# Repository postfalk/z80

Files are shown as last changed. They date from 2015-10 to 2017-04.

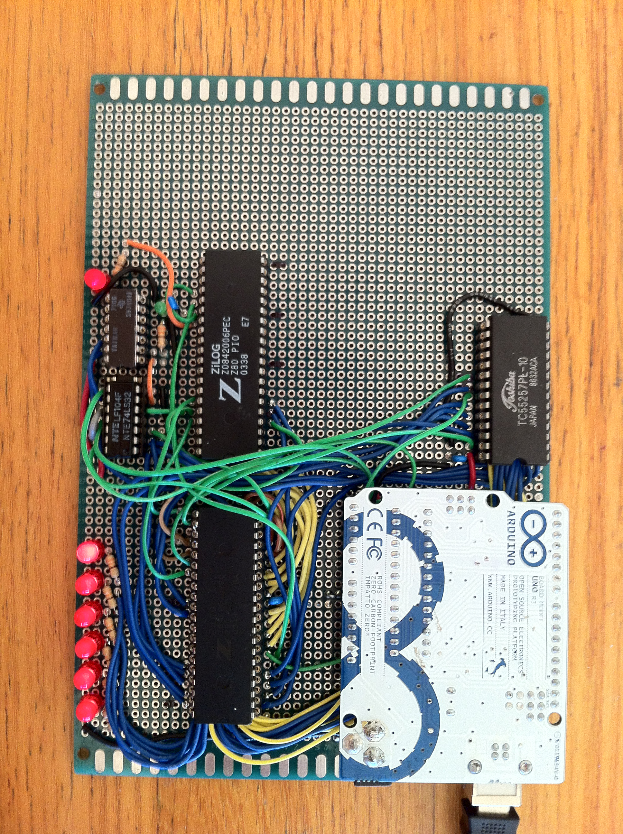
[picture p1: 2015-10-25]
z80_2015_10_25.jpg

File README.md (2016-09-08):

#My Z80 Computer

### Assembler software ####

There is a Z80 assembler in the Ubuntu universe repos!!!

```
sudo apt-get install z80asm 
```

Make sure z80asm is in your executable path. There is also a de-assembler for binaries (z80dasm).

I wrote a simple Python script to automate assembly.

```
python assemble.py -i test.asm
```

In order to review binary hex code install bless:

```
sudo apt-get install bless
```

Most software and examples are written in TASM, I found a compatible project still maintained called ZASM

http://k1.spdns.de/Develop/Projects/zasm/Distributions/

CPM setup

This page proved very useful

http://cpuville.com/cpm_on_new_computer.html

(Currently validating its usefulness)

------------- Much of the below is now obsolete ------------------

**Arduino driven Z80 development**

The Arduino is gone now. Development is fun without it. However, the form factor is still there. Arduino could be used for debugging as needed.

~~The basic idea of this project is to use an Arduino to support the development of a z80 computer system and debug any of its components in the process. The Arduino stands in as ...~~

~~a) reset generator~~
~~b) clock~~
~~c) ROM for the lowest 64byte 0000h-003Fh~~

~~The z80 code is fed from a C array to PORTD, PORTB (with 6pins on an Arduino UNO R3) as address bus, and PORTC simulates the control bus (RD --> PIN4, MRQ --> PIN2, RESET <-- PIN3, CLOCK <-- Pin5). The array index correspondends directly with the z80 system address.~~

~~The z80 board is more or less configured as an Arduino shield (even though bigger, the Arduino is plucked in upside down on top of it). In order to run the board without the Arduino, I created a circuit on an Arduino shield PCB with the reset and clock circuit. Thus, it is possible to go back and forth between normal computer operation and running debug code from Arduino.~~

~~The Arduino emulation runs somewhat over 600khz after stripping all pinMode routines out of the Arduino code. (I wonder whether the ```if ... else ...``` control structure could be replaced with bitwise logic as well).~~

~~After Arduino reset, the Aruino code will perform a z80 reset as well (which needs at least 4 clock cycles).~~

~~The clock speed can be modified by nserting Arduino delays in the code which is very useful for debugging. ```Serial.println``` ~~proved also very useful even though it might conflict with z80 data bus on PORT D. For this reason it needs to be placed strategically (e.g. at the high phase of the clock cycle).~~

A new idea is to use the Arduino as a simple IO device at the Z80 bus. At a 4Mhz clock it would require to use the WAIT signal.

***Prerequisites***

***EEPROM***

I got a very cheap, very universal EEPROM programmer called MiniPro TL866xx. It works perfectly with following project: 
Install the project if you want to use this project to directly write XPROMS with the code below.

https://github.com/vdudouyt/

Tested with [XICOR 28C64] (https://www.jameco.com/Jameco/Products/ProdDS/74827.pdf). The python code below assumes this 8k by 8byte device. Change code accordingly for other devices or more flexible use.

Example use:

````sh
minipro -p X28C64 -w d88_rom.bin
````

***RAM***

http://ee-classes.usc.edu/ee459/library/datasheets/628128.pdf

***Current configuration***

The circuit follows very closely http://www.z80.info/gfx/z80test.gif.

Differences: 

- I am using the more original ZILOG z80 PIO.

*Addresses*:

Memory:  

0000h - 003Fh   Arduino ROM emulation  
or  
0000h - 7FFFh   Space for ROM  
8000h - FFFFh   (static) RAM  

I/O:  

00h - 03h   PIO 
  00h         PORT A - ctrl  
  01h         PORT A - data  
  02h         PORT B - ctrl  
  03h         PORT B - data  
80h - 87h   UART - TL16C550A, documentation: http://www.pci-card.com/TL16C550.pdf

Using the 74HCT138 for address decoding we can address 8 devices (2 of the lines are still unused). The wiring is a little bit unusual here: A - A7, B - A6, C - A5

***Example code in this project***

*piobasics.asm*

Just turns bit 0 at port B on if addresses are configured as above. (any speed, originally 1 to 10hz :) )

*pioextended.asm*

Blinks bit 0 at port B if addresses are configured as above (optimized for, i.e. visible at 600kHz clock). Also requires RAM at ffffh for sub routine call. 

*d88.asm*

A somewhat unsuccessful attempt to drive a I2C 8x8 LED display from Adafruit. The program is able to output a "picture". However, the module used requires continous I2C clock which is hard to provide without timer interrupt. Might pick this project up once CTC interupts are available.

*serial.asm*

Basic implementation of a serial communixcation. Minimal working (output) setup using 9600-8-N-1 configuration:

To set the baud rate, we need to access the divisor registers, which is done by setting the most significant bit of the line control register to 1.

- set register 83 to 80 (1000 0000)

- now set dividers:
  
  * set register 80h to 0ch (12 for 9600)

  * set register 81h to 00h 

- now configure line control register

- set register 83h to 03h

- now transmit data by setting value of register 80h

- check register 85h bit 4 will tell whether transmission register is clear

*bootloader.asm*

- load file from serial port

- assembled code needs to start on 0800h

- file end is determined by time out

- jump to start program

*keyboard.asm*

- simple serial reflector of keyboard activity

- load with bootloader

***Documentation Links***

[Zilog User Manual] (http://www.z80.info/zip/z80cpu_um.pdf)

[CPM User Manual](http://www.cpm.z80.de/manuals/cpm3-usr.pdf)

###Explore

http://www.ecstaticlyrics.com/electronics/SPI/fast_z80_interface.html

[CPM 2.2 installation](http://cpuville.com/cpm_on_new_computer.html): This looks pretty reasonable. I like the idea to use an actual IDE hard disk and do not care about its compatibility outside the system. 

[http://www.glynstore.com/content/docs/ftdi/DS_VDIP2.pdf]: Explore this option to get USB sticks and FAT32 going relatively easily and somewhat lame.

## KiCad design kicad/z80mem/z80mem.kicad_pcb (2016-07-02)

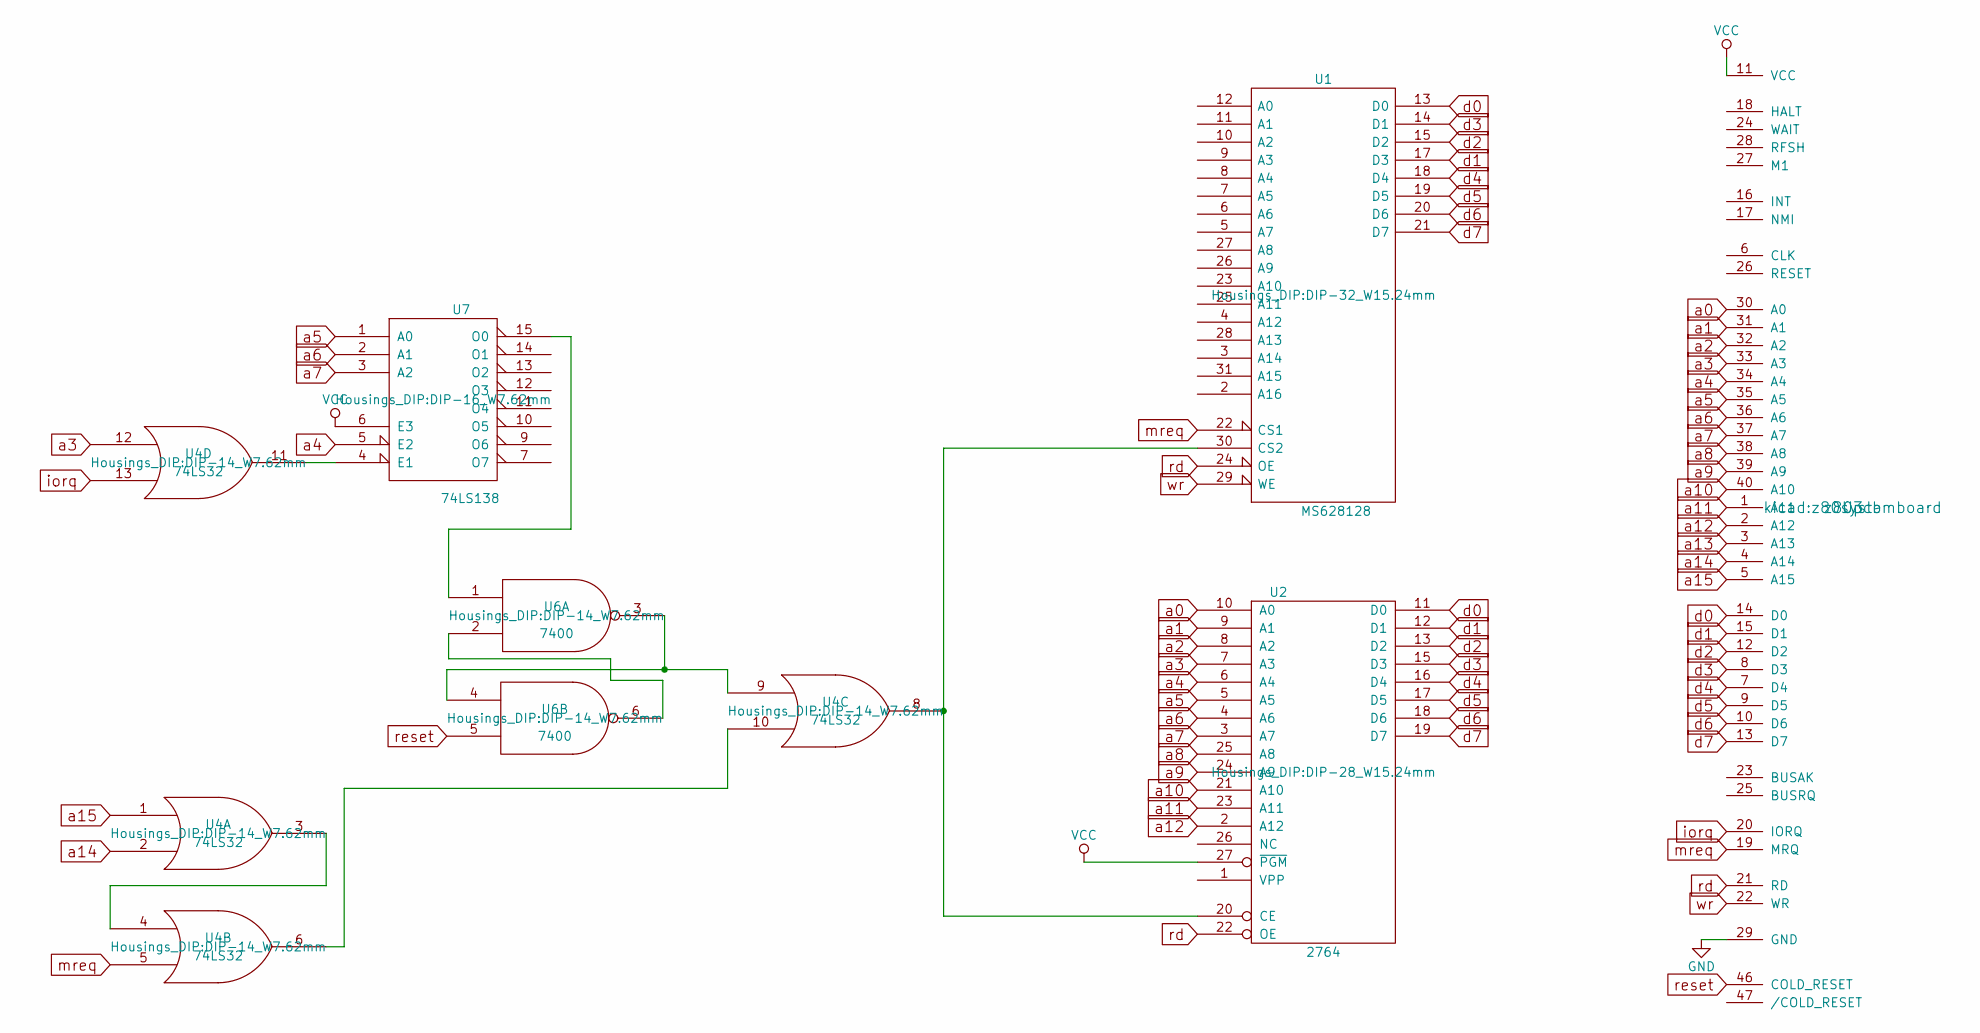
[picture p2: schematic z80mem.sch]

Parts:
U1: MS628128; DIP-32_W15.24mm
U2: 2764; DIP-28_W15.24mm
U3: z80pcb; z80systemboard
U4: 74LS32; DIP-14_W7.62mm
U6: 7400; DIP-14_W7.62mm
U7: 74LS138; DIP-16_W7.62mm

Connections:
GND: U1.16 (GND), U2.14 (GND), U3.29 (GND), U4.7 (GND), U6.7 (GND), U7.8 (GND)
unnamed: U1.30 (CS2), U2.20 (CE), U4.8
unnamed: U4.3, U4.4
unnamed: U4.9, U6.3, U6.4
unnamed: U4.6, U4.10
unnamed: U4.11, U7.4 (E1)
unnamed: U6.1, U7.15 (O0)
unnamed: U6.2, U6.6
VCC: U1.32 (VCC), U2.27 (~PGM), U2.28 (VCC), U3.11 (VCC), U4.14 (VCC), U6.14 (VCC), U7.6 (E3), U7.16 (VCC)
a0: U2.10 (A0), U3.30 (A0)
a1: U2.9 (A1), U3.31 (A1)
a2: U2.8 (A2), U3.32 (A2)
a3: U2.7 (A3), U3.33 (A3), U4.12
a4: U2.6 (A4), U3.34 (A4), U7.5 (E2)
a5: U2.5 (A5), U3.35 (A5), U7.1 (A0)
a6: U2.4 (A6), U3.36 (A6), U7.2 (A1)
a7: U2.3 (A7), U3.37 (A7), U7.3 (A2)
a8: U2.25 (A8), U3.38 (A8)
a9: U2.24 (A9), U3.39 (A9)
a10: U2.21 (A10), U3.40 (A10)
a11: U2.23 (A11), U3.1 (A11)
a12: U2.2 (A12), U3.2 (A12)
a13: U3.3 (A13)
a14: U3.4 (A14), U4.2
a15: U3.5 (A15), U4.1
d0: U1.13 (D0), U2.11 (D0), U3.14 (D0)
d1: U1.17 (D3), U2.12 (D1), U3.15 (D1)
d2: U1.15 (D2), U2.13 (D2), U3.12 (D2)
d3: U1.14 (D1), U2.15 (D3), U3.8 (D3)
d4: U1.18 (D4), U2.16 (D4), U3.7 (D4)
d5: U1.19 (D5), U2.17 (D5), U3.9 (D5)
d6: U1.20 (D6), U2.18 (D6), U3.10 (D6)
d7: U1.21 (D7), U2.19 (D7), U3.13 (D7)
iorq: U3.20 (IORQ), U4.13
mreq: U1.22 (CS1), U3.19 (MRQ), U4.5
rd: U1.24 (OE), U2.22 (OE), U3.21 (RD)
reset: U3.46 (COLD_RESET), U6.5
wr: U1.29 (WE), U3.22 (WR)

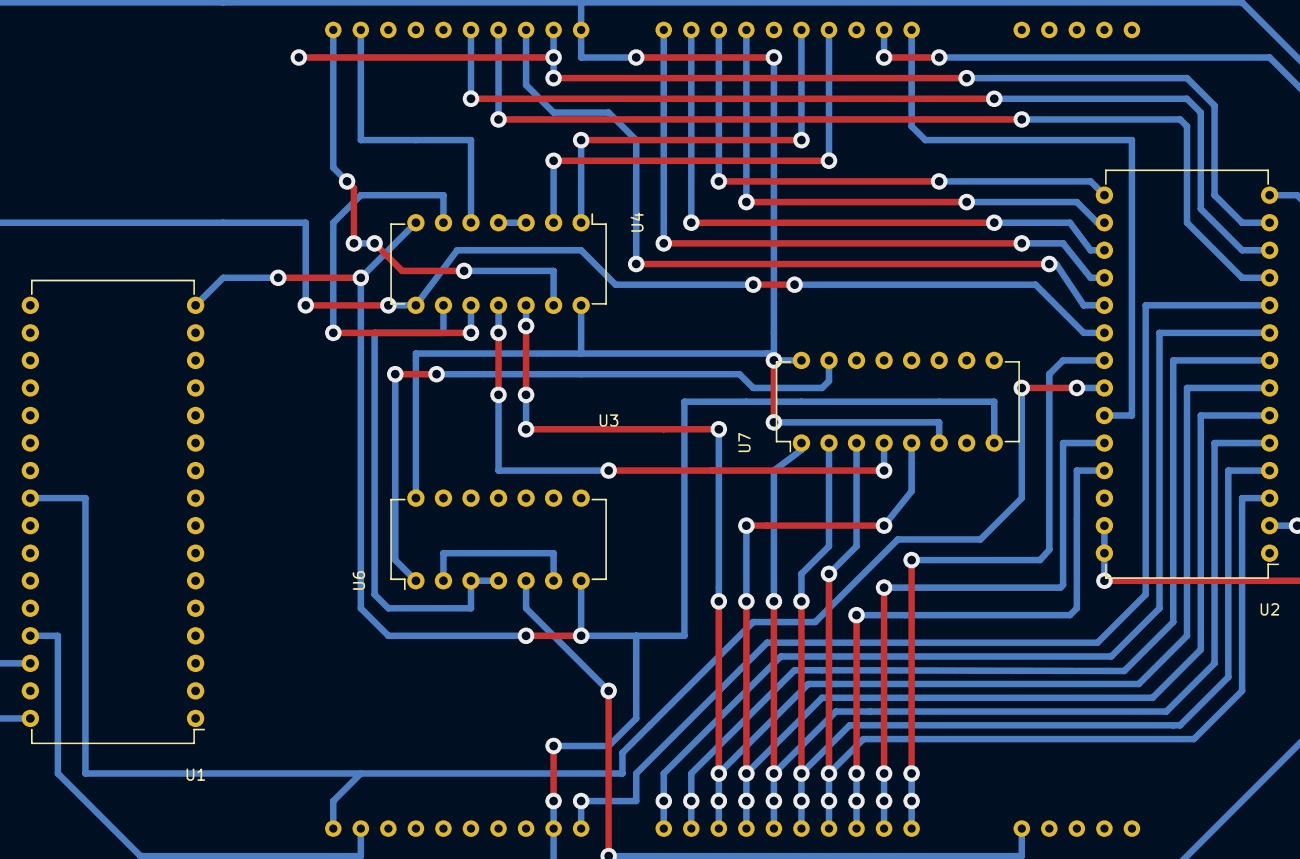
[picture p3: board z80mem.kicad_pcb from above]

Board: 2 copper layers, 6 parts (0 on the bottom side), 37 nets.

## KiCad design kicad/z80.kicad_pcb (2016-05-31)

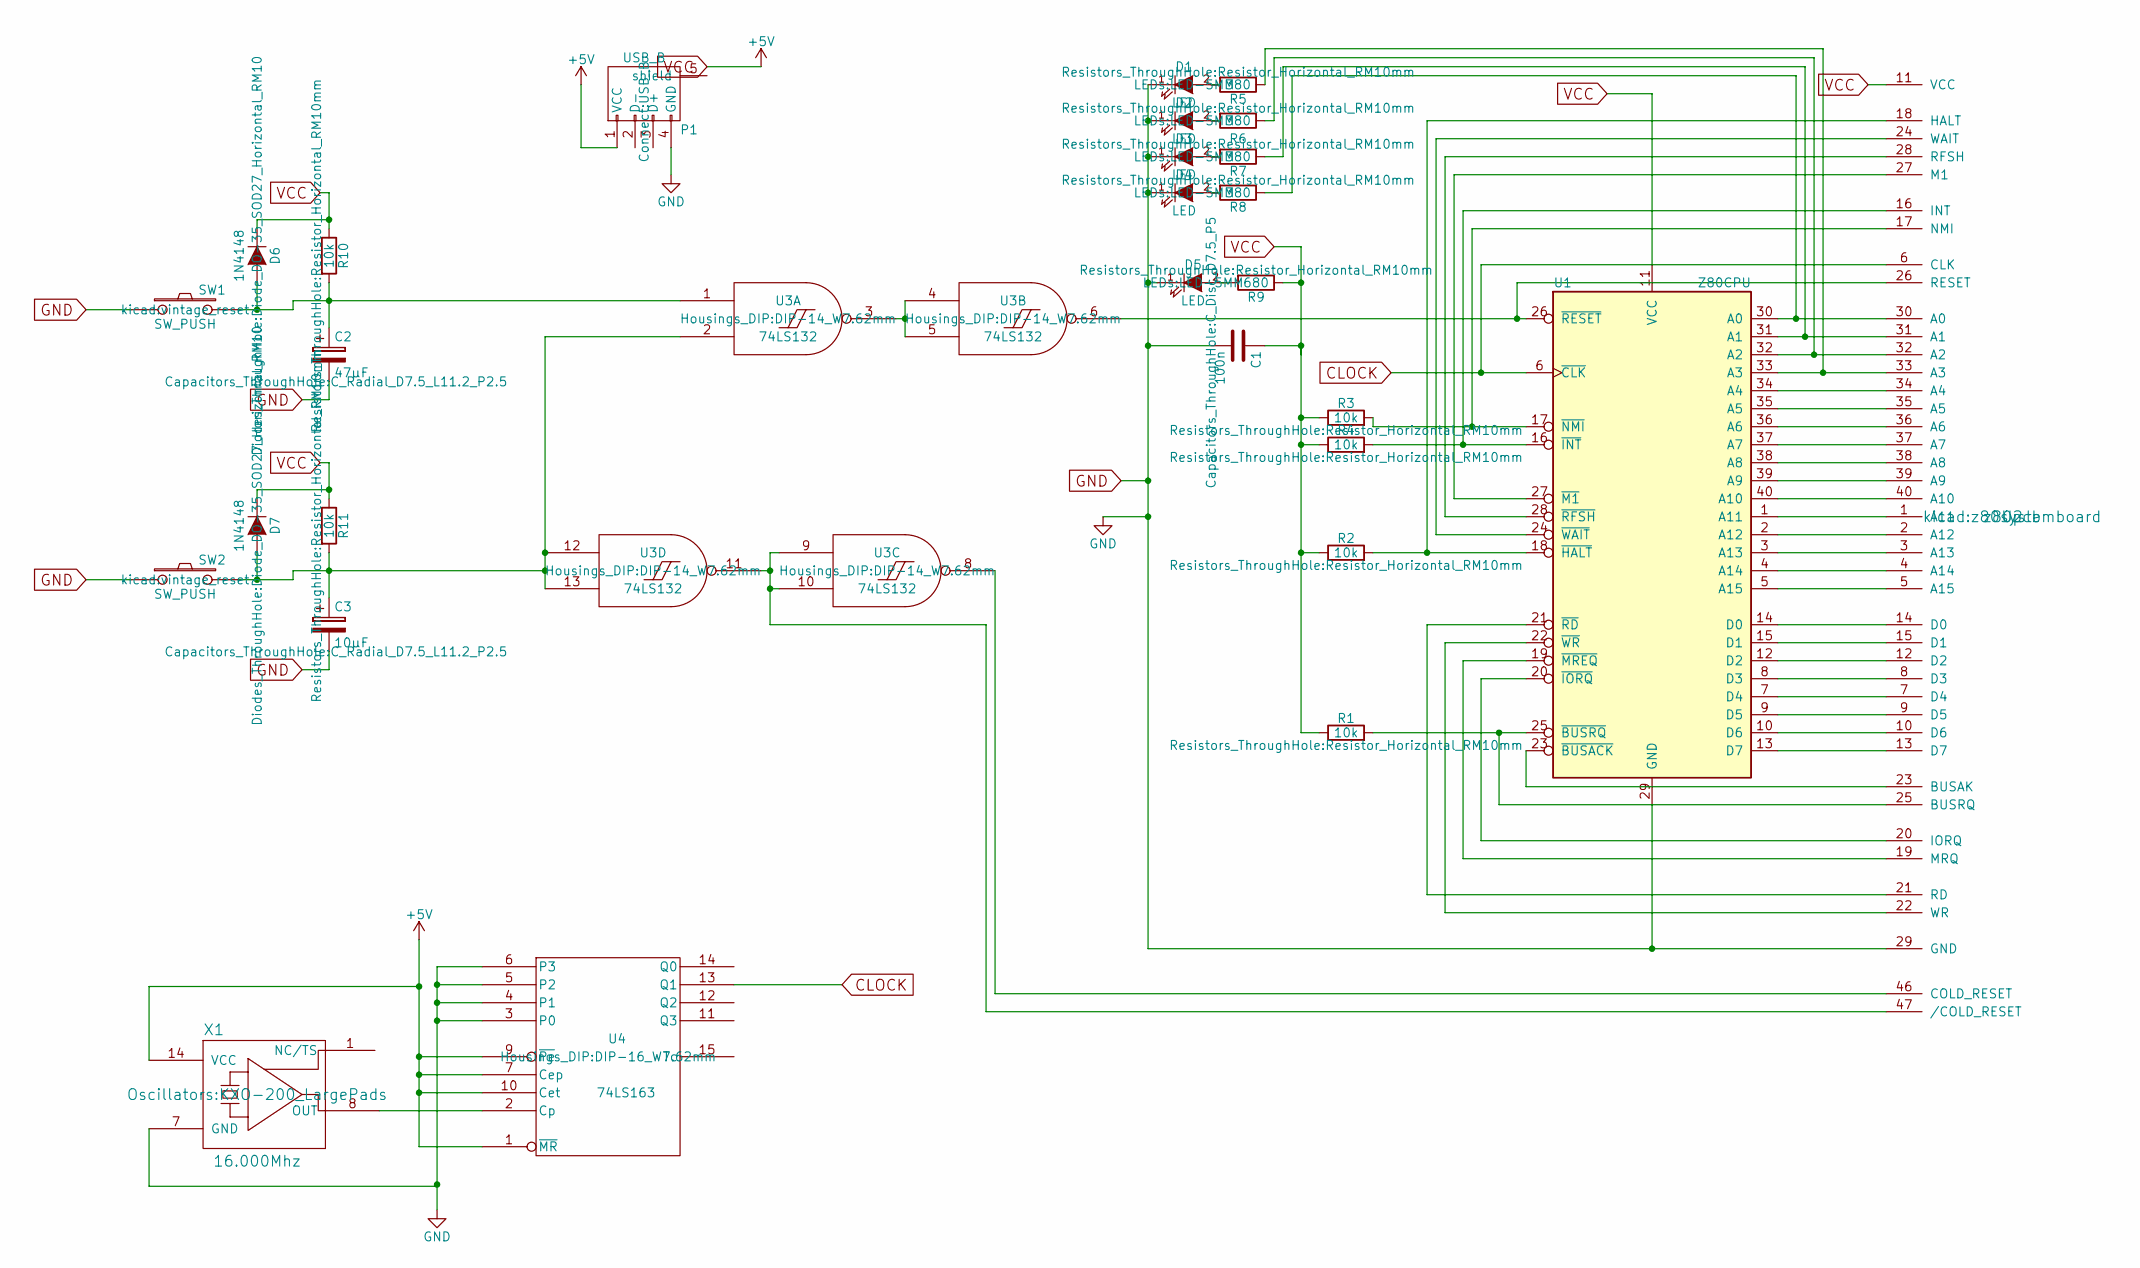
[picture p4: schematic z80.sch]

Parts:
C1: 100n; C_Disc_D7.5_P5
C2: 47μF; C_Radial_D7.5_L11.2_P2.5
C3: 10μF; C_Radial_D7.5_L11.2_P2.5
D1, D2, D3, D4, D5: LED; LED-5MM
D6, D7: 1N4148; Diode_DO-35_SOD27_Horizontal_RM10
P1: USB_B
R1, R2, R3, R4, R10, R11: 10k; Resistor_Horizontal_RM10mm
R5, R6, R7, R8: 380; Resistor_Horizontal_RM10mm
R9: 680; Resistor_Horizontal_RM10mm
SW1, SW2: SW_PUSH; vintage_reset
U1: Z80CPU; DIP-40_W15.24mm
U2: z80pcb; z80systemboard
U3: 74LS132; DIP-14_W7.62mm
U4: 74LS163; DIP-16_W7.62mm
X1: 16.000Mhz; KXO-200_LargePads

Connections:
CLOCK: U1.6 (~CLK~), U2.6 (CLK), U4.13 (Q1)
GND: C1.2, C2.2, C3.2, D1.1 (K), D2.1 (K), D3.1 (K), D4.1 (K), D5.1 (K), P1.4 (GND), SW1.1, SW2.1, U1.29 (GND), U2.29 (GND), U3.7 (GND), U4.3 (P0), U4.4 (P1), U4.5 (P2), U4.6 (P3), U4.8 (GND), X1.7 (GND)
unnamed: C2.1, D6.2 (A), R10.2, SW1.2, U3.1
unnamed: C3.1, D7.2 (A), R11.2, SW2.2, U3.2, U3.12, U3.13
unnamed: D1.2 (A), R5.2
unnamed: D2.2 (A), R6.2
unnamed: D3.2 (A), R7.2
unnamed: D4.2 (A), R8.2
unnamed: D5.2 (A), R9.2
unnamed: R1.2, U1.25 (~BUSRQ~), U2.25 (BUSRQ)
unnamed: R2.2, U1.18 (~HALT~), U2.18 (HALT)
unnamed: R3.2, U1.17 (~NMI~), U2.17 (NMI)
unnamed: R4.2, U1.16 (~INT~), U2.16 (INT)
unnamed: R5.1, U1.33 (A3), U2.33 (A3)
unnamed: R6.1, U1.32 (A2), U2.32 (A2)
unnamed: R7.1, U1.31 (A1), U2.31 (A1)
unnamed: R8.1, U1.30 (A0), U2.30 (A0)
unnamed: U1.1 (A11), U2.1 (A11)
unnamed: U1.2 (A12), U2.2 (A12)
unnamed: U1.3 (A13), U2.3 (A13)
unnamed: U1.4 (A14), U2.4 (A14)
unnamed: U1.5 (A15), U2.5 (A15)
unnamed: U1.7 (D4), U2.7 (D4)
unnamed: U1.8 (D3), U2.8 (D3)
unnamed: U1.9 (D5), U2.9 (D5)
unnamed: U1.10 (D6), U2.10 (D6)
unnamed: U1.12 (D2), U2.12 (D2)
unnamed: U1.13 (D7), U2.13 (D7)
unnamed: U1.14 (D0), U2.14 (D0)
unnamed: U1.15 (D1), U2.15 (D1)
unnamed: U1.19 (~MREQ~), U2.19 (MRQ)
unnamed: U1.20 (~IORQ~), U2.20 (IORQ)
unnamed: U1.21 (~RD~), U2.21 (RD)
unnamed: U1.22 (~WR~), U2.22 (WR)
unnamed: U1.23 (~BUSACK~), U2.23 (BUSAK)
unnamed: U1.24 (~WAIT~), U2.24 (WAIT)
unnamed: U1.26 (~RESET~), U2.26 (RESET), U3.6
unnamed: U1.27 (~M1~), U2.27 (M1)
unnamed: U1.28 (~RFSH~), U2.28 (RFSH)
unnamed: U1.34 (A4), U2.34 (A4)
unnamed: U1.35 (A5), U2.35 (A5)
unnamed: U1.36 (A6), U2.36 (A6)
unnamed: U1.37 (A7), U2.37 (A7)
unnamed: U1.38 (A8), U2.38 (A8)
unnamed: U1.39 (A9), U2.39 (A9)
unnamed: U1.40 (A10), U2.40 (A10)
unnamed: U2.46 (COLD_RESET), U3.8
unnamed: U2.47 (/COLD_RESET), U3.9, U3.10, U3.11
unnamed: U3.3, U3.4, U3.5
unnamed: U4.2 (Cp), X1.8 (OUT)
VCC: C1.1, D6.1 (K), D7.1 (K), P1.1 (VCC), R1.1, R2.1, R3.1, R4.1, R9.1, R10.1, R11.1, U1.11 (VCC), U2.11 (VCC), U3.14 (VCC), U4.1 (~MR), U4.7 (Cep), U4.9 (~Pe), U4.10 (Cet), U4.16 (VCC), X1.14 (VCC)

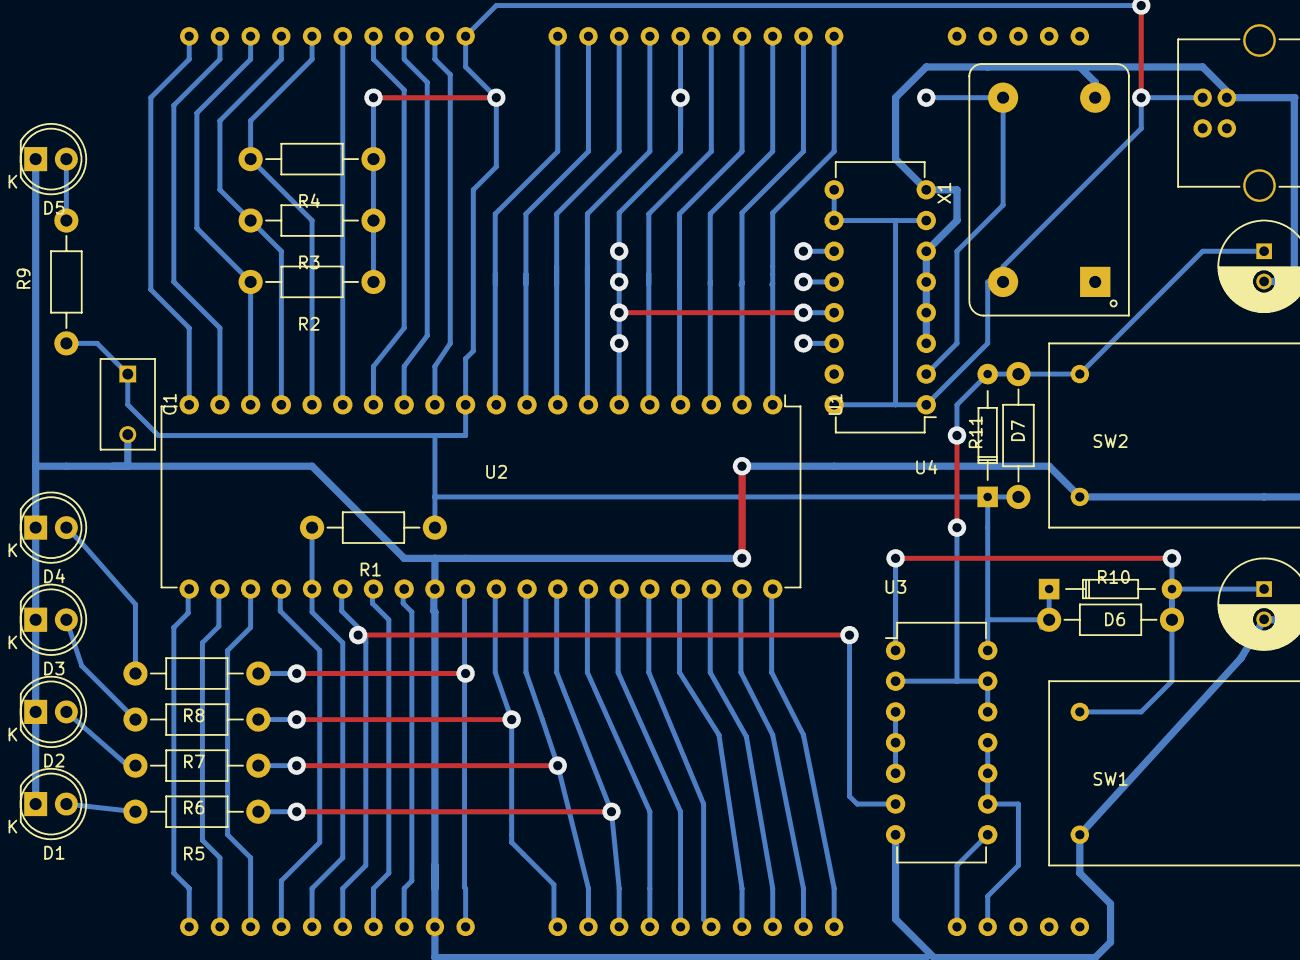
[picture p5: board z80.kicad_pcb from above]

Board: 2 copper layers, 29 parts (0 on the bottom side), 51 nets.

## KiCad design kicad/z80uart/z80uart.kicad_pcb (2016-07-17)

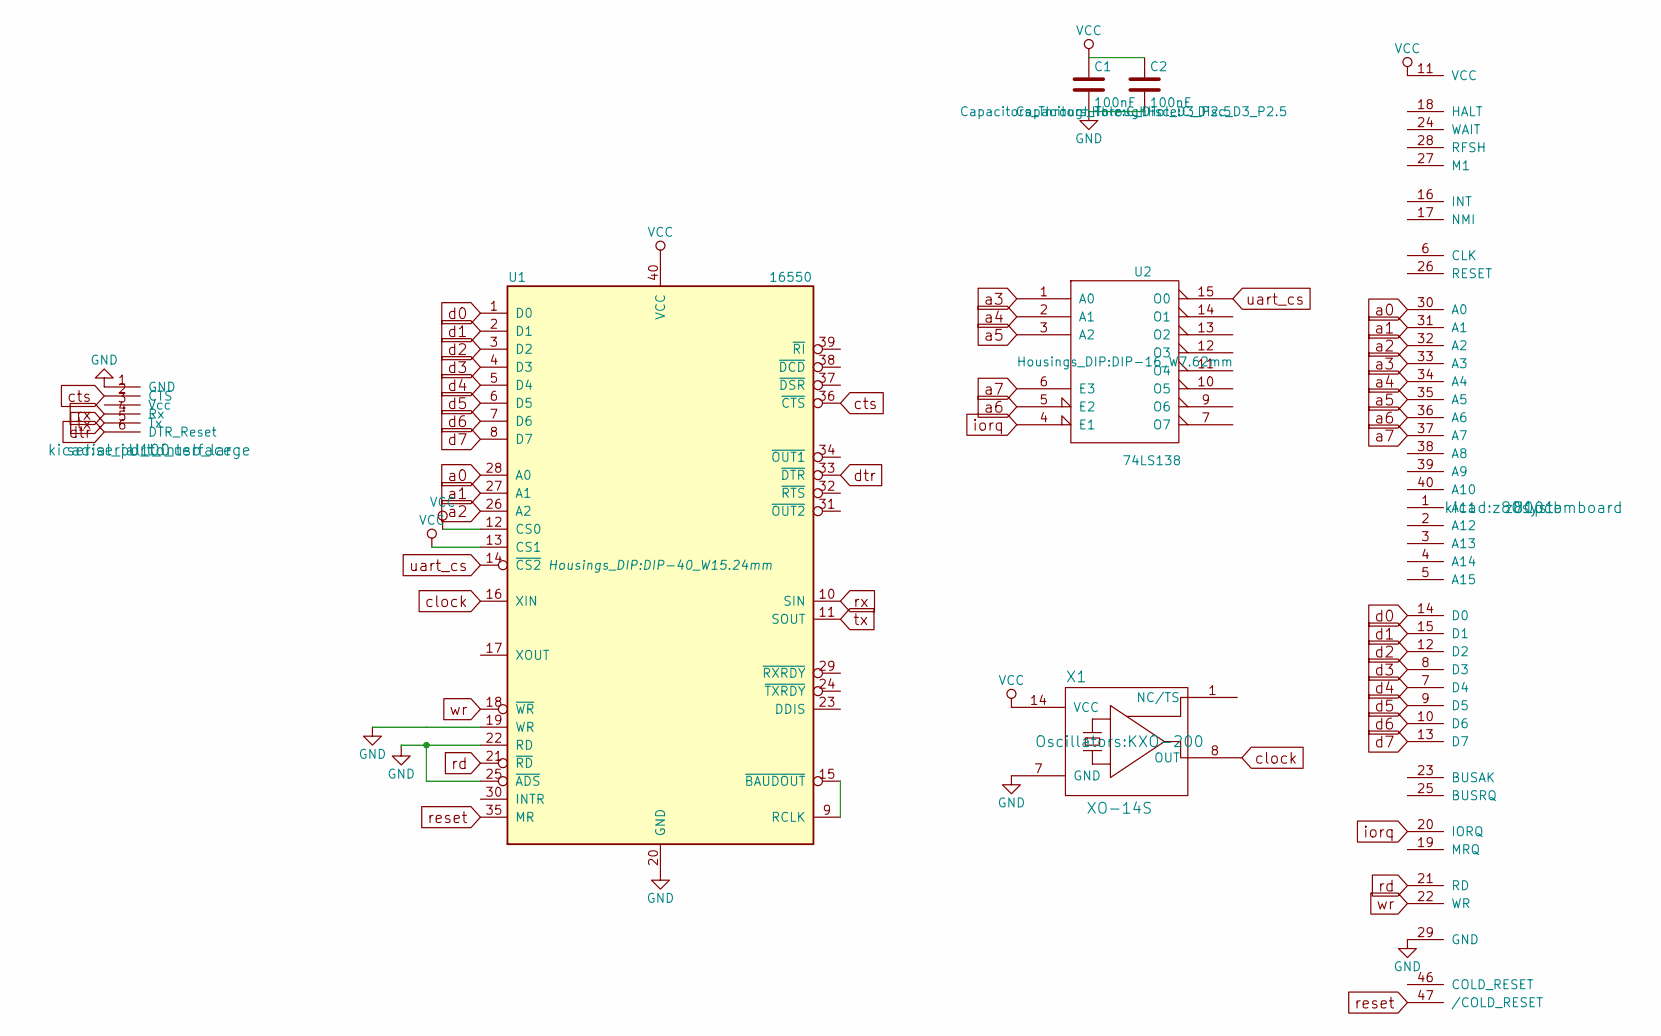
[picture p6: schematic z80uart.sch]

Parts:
C1, C2: 100nF; C_Disc_D3_P2.5
U1: 16550; DIP-40_W15.24mm
U2: 74LS138; DIP-16_W7.62mm
U100: serial_port_interface; serial_to_usb_large
U101: z80pcb; z80systemboard
X1: XO-14S; KXO-200

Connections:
unnamed: U1.9 (RCLK), U1.15 (~BAUDOUT~)
a0: U1.28 (A0), U101.30 (A0)
a1: U1.27 (A1), U101.31 (A1)
a2: U1.26 (A2), U101.32 (A2)
a3: U2.1 (A0), U101.33 (A3)
a4: U2.2 (A1), U101.34 (A4)
a5: U2.3 (A2), U101.35 (A5)
a6: U2.5 (E2), U101.36 (A6)
a7: U2.6 (E3), U101.37 (A7)
clock: U1.16 (XIN), X1.8 (OUT)
cts: U1.36 (~CTS~), U100.2 (CTS)
d0: U1.1 (D0), U101.14 (D0)
d1: U1.2 (D1), U101.15 (D1)
d2: U1.3 (D2), U101.12 (D2)
d3: U1.4 (D3), U101.8 (D3)
d4: U1.5 (D4), U101.7 (D4)
d5: U1.6 (D5), U101.9 (D5)
d6: U1.7 (D6), U101.10 (D6)
d7: U1.8 (D7), U101.13 (D7)
dtr: U1.33 (~DTR~), U100.6 (DTR_Reset)
iorq: U2.4 (E1), U101.20 (IORQ)
rd: U1.21 (~RD~), U101.21 (RD)
reset: U1.35 (MR), U101.47 (/COLD_RESET)
rx: U1.10 (SIN), U100.4 (Rx)
tx: U1.11 (SOUT), U100.5 (Tx)
uart_cs: U1.14 (~CS2~), U2.15 (O0)
wr: U1.18 (~WR~), U101.22 (WR)

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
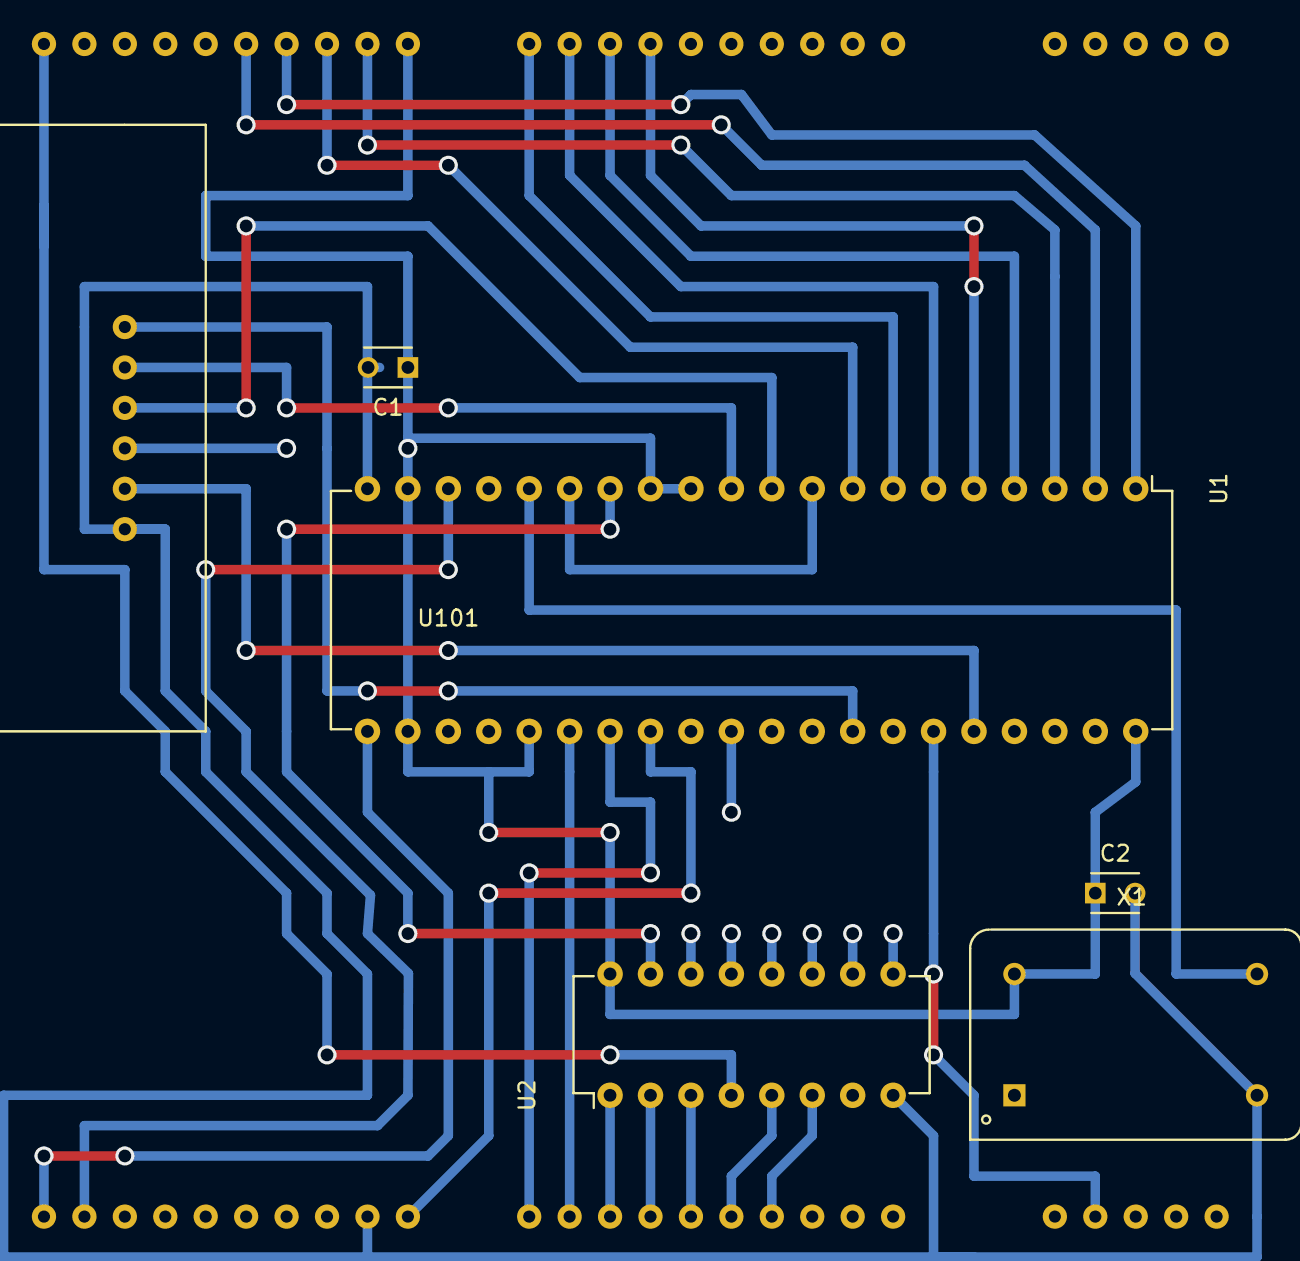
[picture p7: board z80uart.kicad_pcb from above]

Board: 2 copper layers, 7 parts (0 on the bottom side), 29 nets.

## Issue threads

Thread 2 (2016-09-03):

Create running Microsoft BASIC for current setup

postfalk, 2016-09-03:
... just for fun. Use this for directions to run from ROM:

http://searle.hostei.com/grant/z80/SimpleZ80.html#RomBasic

Not sure why interrupt is needed here. But I will go for it without it or just wire up the Interrupt as in the example (which needs an additional NOT gate unfortunately).

postfalk, 2017-04-30:
Still working on this one. Why does this thing does not get math right?

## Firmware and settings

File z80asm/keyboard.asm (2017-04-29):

;;;;;;;;;;;;;;;;;;;;;;;;;;;;;;;;;;;;;;;;;;;;;;;;;;;;;;;;;;;;;;;;;;;;;;;;;;
;                                                                        ;
;   Simple Typing and reflecting input back to UART                      ;
;                                                                        ;
;                                                                        ;
;;;;;;;;;;;;;;;;;;;;;;;;;;;;;;;;;;;;;;;;;;;;;;;;;;;;;;;;;;;;;;;;;;;;;;;;;;

org 00000h 

setup:              ld sp, 0ffffh       ; set stack pointer
                    ld a, 080h          ; UART: initialize
                    out (083h), a       ; UART: enable access to the divisor regs
                    ld a, 0ch           ; UART: set divisor to 12, causes 9600 
                    out (080h), a       ; baud rate
                    ld a, 00h           ; UART: set least significant bit of divisor
                    out (081h), a
                    ld a, 03h           ; UART: set serial mode to 8-N-1
                    out (083h), a

loop:               ld hl, newline      ; output some user friendly instructions
                    call print
                    ld hl, text
                    call print
                    ld hl, newline
                    call print
    loop1:          in a, (085h)
                    and 001h
                    jr z, loop1
                    call serial_in
                    ld c, a
                    call serial_out
                    ; ld hl, 08000h     ; reflect loaded data
                    ; call print
                    jp loop1            ; just hanging out here

print:              ld c, (hl)          ; load byte
                    inc hl              ; move pointer up
                    call serial_out     ; send byte to output
                    sub 00ah            ; check for end of line
                    jr nz, print        ; next byte if not eol
                    ret

load:               in a, (085h)        ; check whether data available
                    and 001h
                    jr z, load          ; wait here until transmission
    load_1:         call serial_in      ; read byte
                    ld (hl), a          ; write byte to memory
                    inc hl              ; next address
                    ; sub 00ah
                    inc b               ; check whether timeout occurred
                    dec b
                    jr nz, load_1       ; load next character if not timeout
                    ret

serial_out:         in a, (085h)        ; read line status register
                    and 040h            ; check transmitter empty
                    jr z, serial_out    ; wait until transmitter empty=1
                    ld a, c
                    out (080h), a       ; send byte
                    ret

serial_in:          ld b, 0ffh          ; set timeout counter
    serial_in_1:    in a, (085h)        ; read line status register
                    dec b               ; dec timeout counter
                    jr z, return        ; check timeout
                    and 001h            ; check data ready
                    jr z, serial_in_1   ; wait until data ready=1
                    in a, (080h)
    return:         ret

; set relative wait time in bc
wait:               push de             ; protect affected registers
                    push af
    outer:          ld de, 0100h
        inner:      dec de
                    ld a, d
                    or e
                    jp nz, inner
                    dec bc
                    ld a, b
                    or c
                    jp nz, outer
                    pop af
                    pop de
                    ret

; store data here
newline:            db "\r\n"
text:               db "Start typing ...\r\n"
loaded:             db "Data loaded.\r\n"

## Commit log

2015-10-23 speeding up Arduino code by factor 15
2016-05-01 add kicad files
    [z80.kicad_pcb, z80.sch]
2016-05-03 add reset circuit
    [z80.kicad_pcb, z80.sch]
2016-05-05 fixed connections
    [_saved_z80.sch, z80.kicad_pcb, z80.sch]
2016-05-31 finish cpu board draft
    [_saved_z80.sch, z80.kicad_pcb, z80.sch]
2016-06-07 add memory card
    [z80mem.kicad_pcb, z80mem.sch]
2016-07-02 add some unfished pcbs
    [z80mem.kicad_pcb, z80mem.sch, z80uart.kicad_pcb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]
2016-07-02 add simple CPM mem switch test
2016-07-17 add uart
    [z80uart.kicad_pcb, z80uart.sch]
2016-09-03 add UART board
    [_saved_z80uart.sch]
2016-09-03 Add assembler notes to README.md
2017-04-29 well al lot of stuff since I committed last time
    [_saved_z80uart.sch, z80.kicad_pcb, z80.sch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]
